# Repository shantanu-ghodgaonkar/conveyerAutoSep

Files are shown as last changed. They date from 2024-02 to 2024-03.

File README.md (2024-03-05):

# conveyerAutoSep

Automatic Package Separator with Arduino
Abstract:

This project builds an innovative Automatic Package Separator system using Arduino technology. It aims to streamline and enhance the efficiency of package segregation based on their addresses.

[Please watch the video by downloading the raw file](IMG_8251.mp4)

Key Components:

Arduino Microcontroller: Manages the system, integrating various components and enabling communication.
1D/2D Barcode Scanner: Uses Waveshare scanner with UART protocol for accurate address reading.
Servo Motors: Control the conveyor system, ensuring precise package movement.
DC Motor: Converts electrical energy into rotational movement for the conveyor.
Ultrasonic Sensor: Measures distances for object detection and avoidance.
LCD Display Module: Provides real-time information.
Operational Overview:

Address Detection: The 2D barcode scanner reads package addresses quickly and accurately.
Conveyor Actuation: Arduino and servo motors control the conveyor. Upon address detection, the motors guide packages towards designated bins.
Segregation Mechanism: Servo motors divert packages to specific bins based on their barcode addresses.
Introduction:

This project addresses the demand for innovative solutions in logistics and supply chain management, specifically focusing on package handling optimization. It introduces an Arduino-driven Automatic Package Separator to revolutionize the process using 1D/2D barcode scanning.

Problem Statement:

Traditional manual sorting processes are time-consuming, error-prone, and resource-intensive. This project aims to automate package segregation based on addresses, mitigating errors and increasing efficiency.

Technological Foundation:

Arduino Uno Microcontroller: The project's core, chosen for its compact size and capabilities.
1D/2D Barcode Scanner (Waveshare): Reads 1D/2D barcodes accurately and efficiently.
Operational Mechanism:

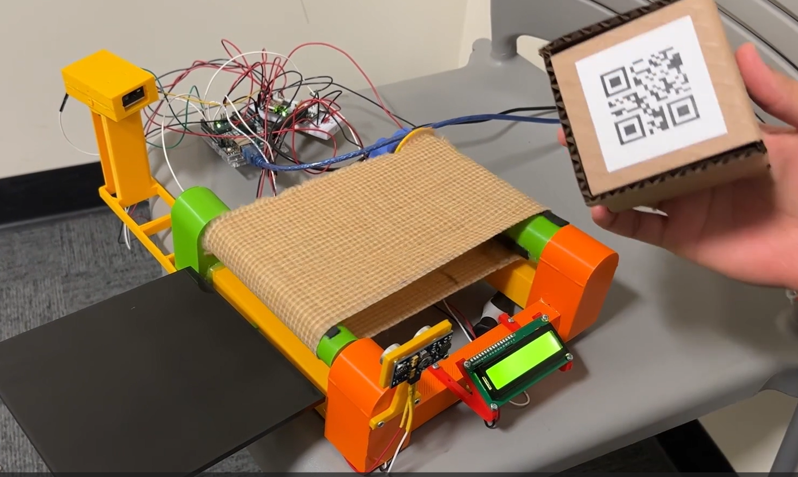
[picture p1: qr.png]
<br/>

Address Detection: The barcode scanner reads package addresses as they pass through the scanning point.
Arduino Uno Control: The Arduino processes scanned information, interpreting the package's destination.
Conveyor Mechanism: A DC motor, controlled by Arduino, actuates the conveyor. Upon address detection, the Arduino commands servo motors to guide the package towards the designated bin.
Segregation Mechanism: A dual-axis turntable with servo motors rotates along two axes, allowing packages to be directed to specific bins.
Components:

Servo Motors: Two control rotation on each axis.
Turntable Platform: Holds the object being rotated.
Turntable Mount: Holds the servo motors, mounted on the conveyor body.
Base Structure: Supports the turntable platform for stability.
Parallax PING))) Ultrasonic Sensor: Measures distances for object detection.
Relay: An electrically operated switch.
LCD Display Module: Provides real-time information.
Technological Choice:

2D barcode scanning is chosen for its proven simplicity and efficiency, enhancing address detection accuracy.

Project Objectives:

Minimize manual effort.
Decrease sorting errors.
Significantly improve speed and accuracy.
Future Enhancements:

Machine Learning Integration: Optimize sorting algorithms based on data, package types, and destinations.
Robotics Integration: Explore robots for automated package handling.
Cascaded Network of Modules: Integrate multiple systems for multilevel sorting.
This document serves as a comprehensive overview of the Automatic Package Separator project. It details the system design, functionalities, and potential future enhancements.

Segregation for Brooklyn-
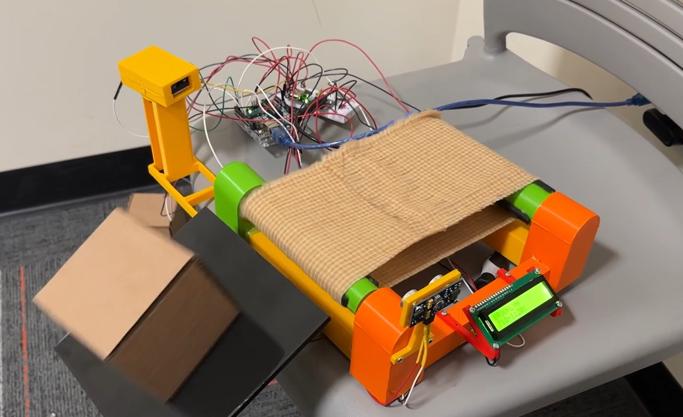
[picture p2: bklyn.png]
<br/>

Segregation for Manhattan-
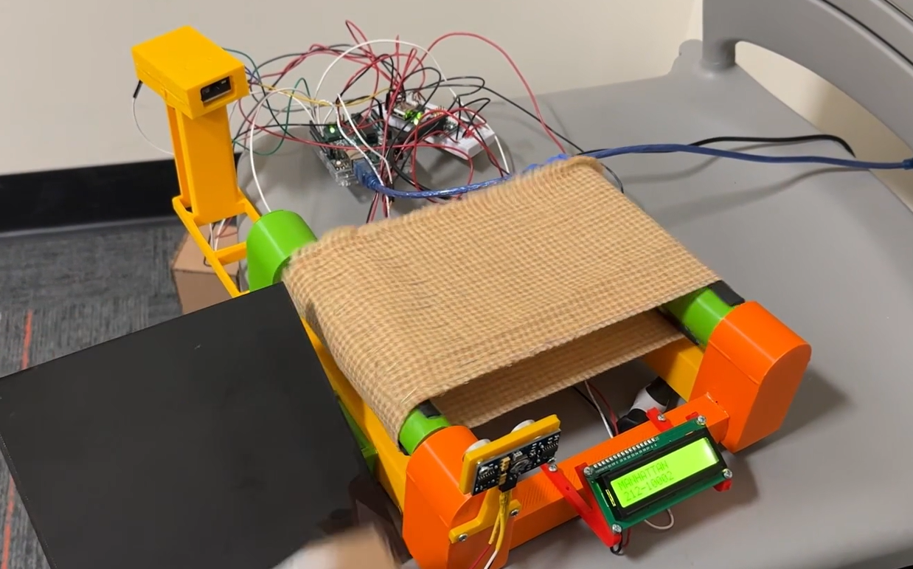
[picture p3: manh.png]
<br/>

Segregation for Queens-
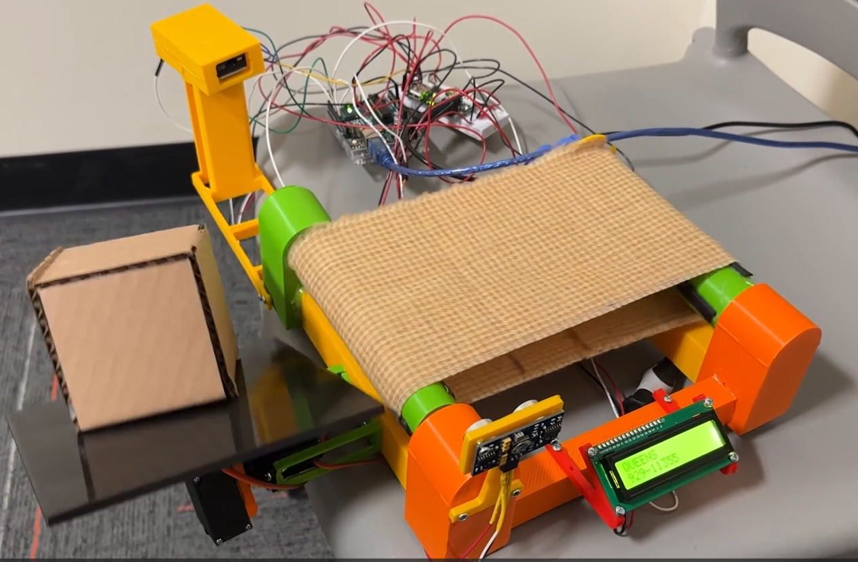
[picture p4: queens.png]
<br/>

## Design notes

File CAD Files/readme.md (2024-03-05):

This folder stores all the CAD files for building the conveyer system.

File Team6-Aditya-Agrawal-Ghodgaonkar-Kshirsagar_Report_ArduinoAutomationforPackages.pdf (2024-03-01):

# Automated Package Separator

By:

Shantanu Ghodgaonkar | - | sng8399, N11344563
Hemant Agarwal | - | hra5704, N10037896
Mihir Kshirsagar | - | msk9917, N16144406
Aditya Abishai Pedapati | - | aap9224, N15101231

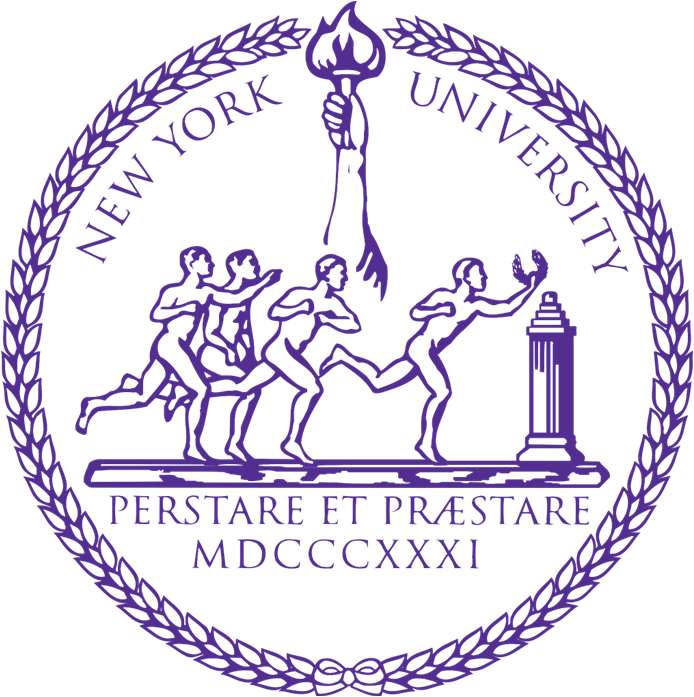
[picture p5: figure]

## New York University, Tandon School of Engineering Department of Mechanical and Aerospace Engineering Advanced Mechatronics ROB-GY6103 Term Project -1

1

CONTENTS

### 1. Acknowledgements 2. Abstract

a. Key Components
b. Operational Overview

### 3. Introduction 4. Problem Statement 5. Technological Foundation

a. 1D/2D Barcode Scanner
b. Operational Mechanism
c. Arduino Uno Control
d. Conveyer Mechanism
e. Segregation Mechanism
i. Components of Segregation Mechanism

### 1. Turntable Platform 2. Turntable mount 3. Base Structure

f. Parallax PING)))
g. Relay
h. LCD Display Module

### 6. Technological Choice 7. Project Objectives 8. Circuit Schematics 9. Flowcharts

10.Applications
11.Future Enhancements
12.References

2

Acknowledgements
We extend our heartfelt gratitude to Professor Vikram Kapila PhD, for his invaluable mentorship and scholarly guidance throughout our academic journey. His expertise and dedication have inspired us, shaping our understanding and passion for the subject.

To our teammates, Shantanu Ghodgaonkar, Mihir Kshirsagar, Hemant Agarwal and Aditya Abishai P we appreciate the collaborative effort and camaraderie that made our academic endeavors even more rewarding.

This journey would not have been possible without the support and encouragement of these exceptional individuals. Thank you for being constant pillars of knowledge and inspiration in our academic endeavors."

Abstract

This project revolves around the development of an innovative Automatic Package Separator system using Arduino technology. The primary objective is to streamline and enhance the efficiency of package segregation based on their respective addresses.

Key Components:

Arduino Microcontroller: The core of the system, managing the integration of various components and facilitating seamless communication.
1D/2D Barcode Scanner (Waveshare): Utilizing the Waveshare barcode scanner with UART communication protocol for accurate and efficient address detection.
Servo Motors: Employing multiple servo motors to actuate the conveyor system, ensuring precise and controlled movement of packages.
DC Motor: A DC motor converts direct current (DC) electrical energy into rotational mechanical energy
Ultrasonic Sensor: The Parallax PING))) Ultrasonic Sensor utilizes ultrasonic sound waves to measure distances and is commonly employed for object detection, navigation, and avoidance in various projects.
LCD Display Module: An LCD (Liquid Crystal Display) module is a versatile electronic visual display that is commonly used to provide real-time information in various devices.

Operational Overview:

1D/2D Barcode Address Detection: The system employs a 2D barcode scanner for quick and accurate reading of package addresses. The simplicity and efficiency of 2D barcodes contribute to the speed and reliability of the detection process.
Conveyor Actuation: Arduino, in collaboration with servo motors, controls the conveyor system. Upon successful address detection, the servo motors activate, guiding the packages towards their designated bins for further processing.
Segregation Mechanism: The servo motors play a crucial role in diverting packages to specific bins based on their 1D barcode addresses. This automated approach ensures a systematic and errorfree package segregation process.

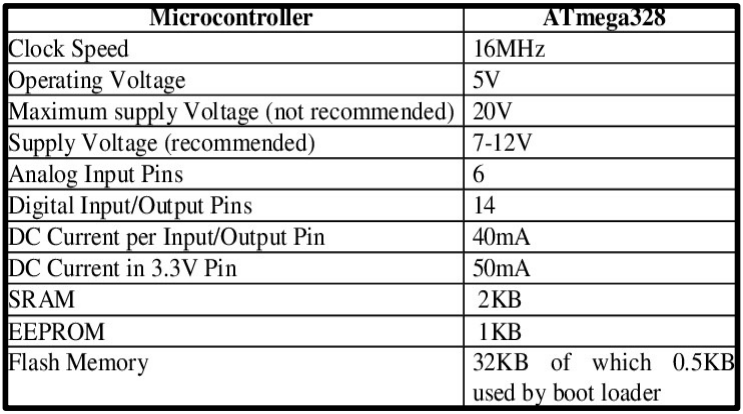
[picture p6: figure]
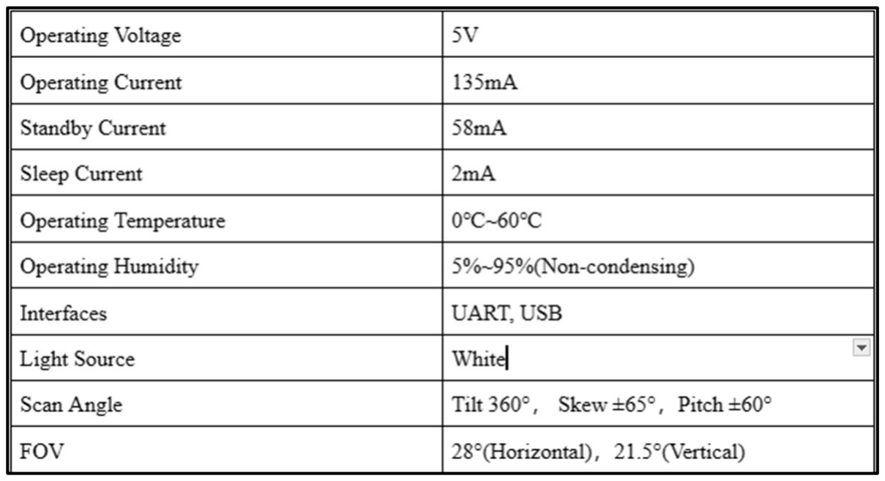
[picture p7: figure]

3

- Introduction

In the dynamic landscape of logistics and supply chain management, the demand for innovative solutions to optimize package handling has never been more critical. This project endeavors to meet this demand by introducing an Automatic Package Separator, a sophisticated system driven by Arduino Uno, designed to revolutionize the segregation process through the incorporation of a 1D/2D barcode scanner.

- Problem Statement
Traditional manual sorting processes are inherently time-consuming, error-prone, and resourceintensive. In response to these challenges, our project aims to automate the segregation of packages based on their addresses, mitigating errors and significantly increasing operational efficiency.
- Technological Foundation

Arduino Uno Microcontroller: At the core of our system lies the Arduino Uno, a versatile and widely-used microcontroller. Its compact size and capabilities make it a suitable choice for coordinating the various components of our Automatic Package Separator.

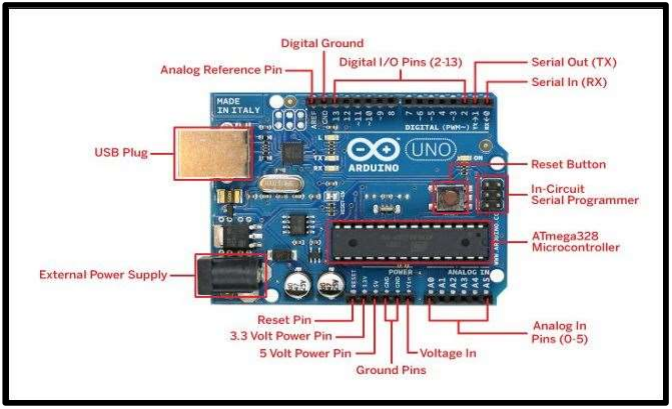
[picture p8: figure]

- 1D/2D Barcode Scanner (Waveshare)
The heart of our address detection mechanism is the Waveshare 1D/2D barcode scanner, utilizing a UART communication protocol. This scanner is strategically chosen for its accuracy, efficiency, and simplicity in reading 1D/2D barcodes.

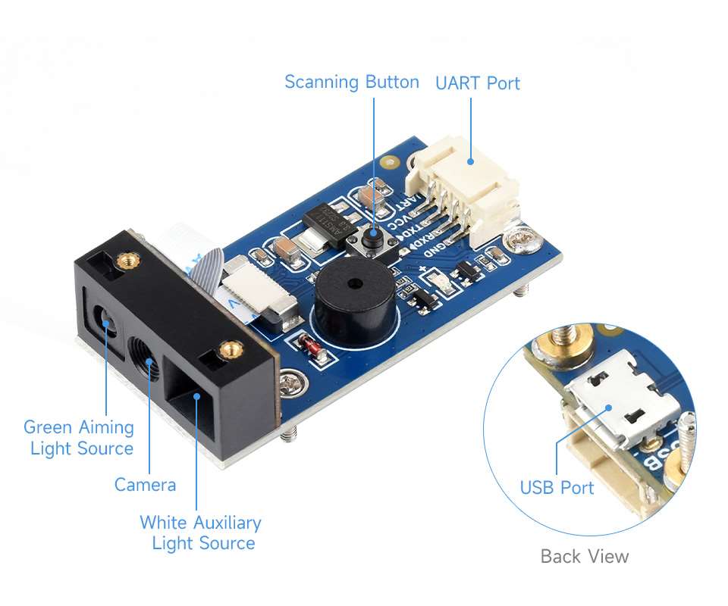
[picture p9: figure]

Specifications of the Barcode scanner

4

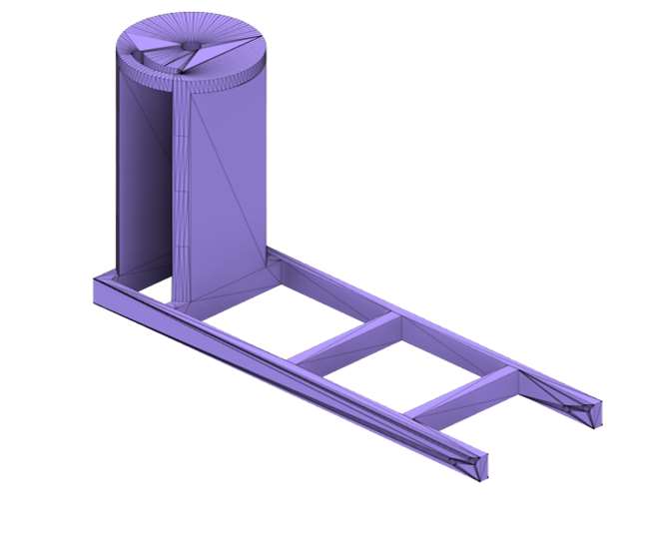
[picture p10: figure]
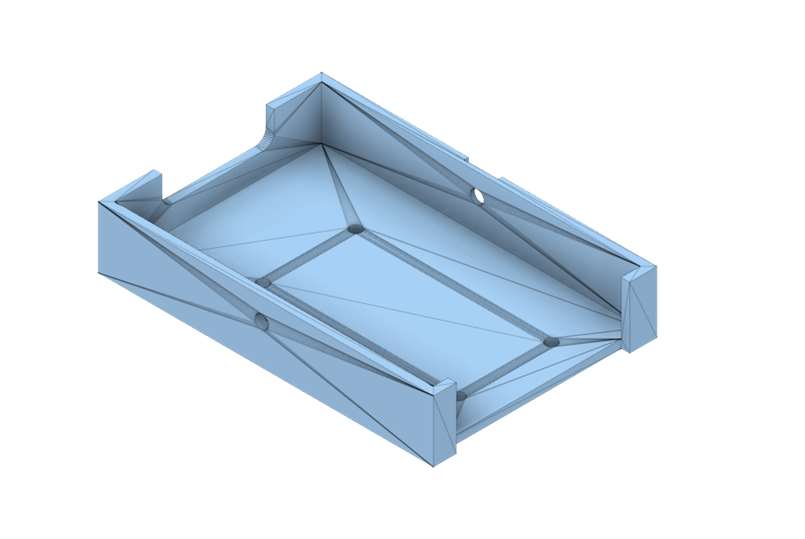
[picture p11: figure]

barcode scanner housing | Barcode scanner mount
- Operational Mechanism

Address Detection: The 1D/2D barcode scanner is integrated into the system to facilitate the swift and accurate reading of package addresses. As a package passes through the scanning point, the barcode scanner decodes the information embedded in the 2D QR code.

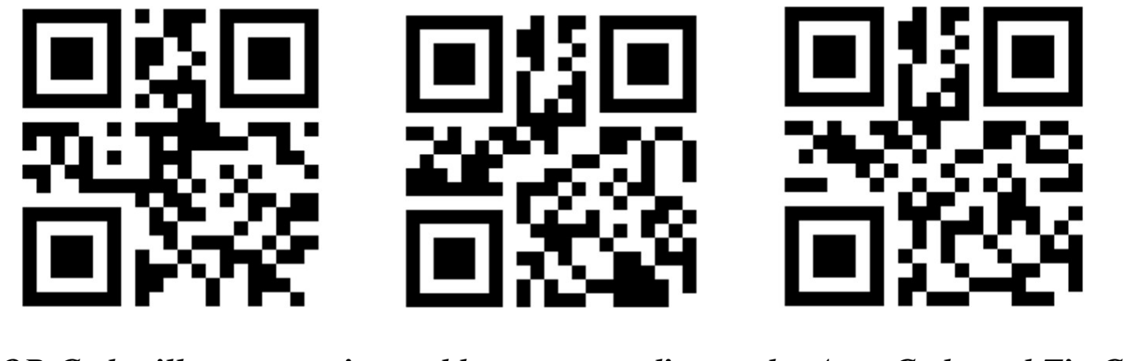
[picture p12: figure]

The QR Codes illustrate various addresses according to the Area Code and Zip Code of NYC’s Brooklyn(718-11201), Queens(929-11355) and Manhattan(212-10002)

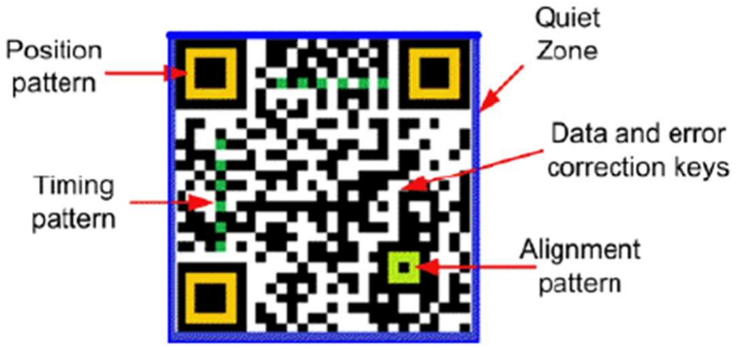
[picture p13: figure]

- Arduino Uno Control
The Arduino Uno processes the information received from the barcode scanner, leveraging its processing power to interpret the package's destination based on the scanned address. This information serves as the trigger for the subsequent stages of the segregation process.

5

- Conveyor Mechanism
One DC motor, intricately connected to the Arduino Uno, is employed to actuate the conveyor system. Upon successful address detection, the Arduino commands the servo motors to guide the package towards its designated bin.

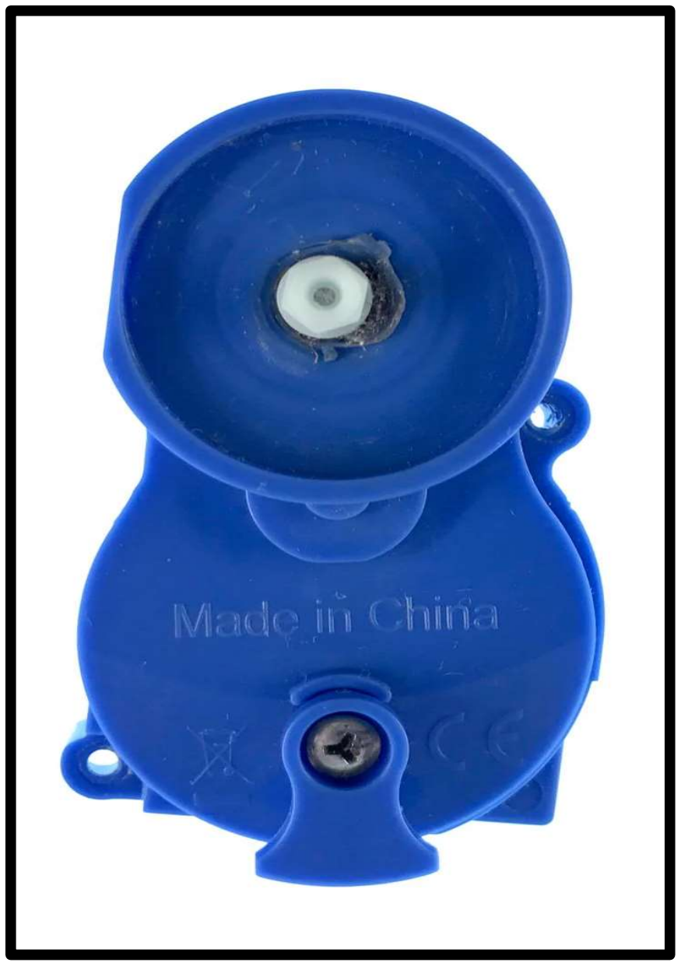
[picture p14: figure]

- Segregation Mechanism

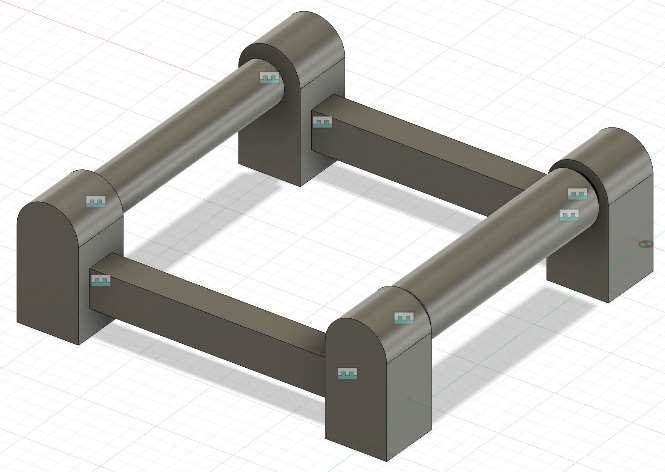
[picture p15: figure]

A dual-axis turntable with servomotors is a mechanism that allows for rotation along two independent axes. This type of system is commonly used in applications such as robotics, photography, or any scenario where precise control of rotation in two dimensions is required.

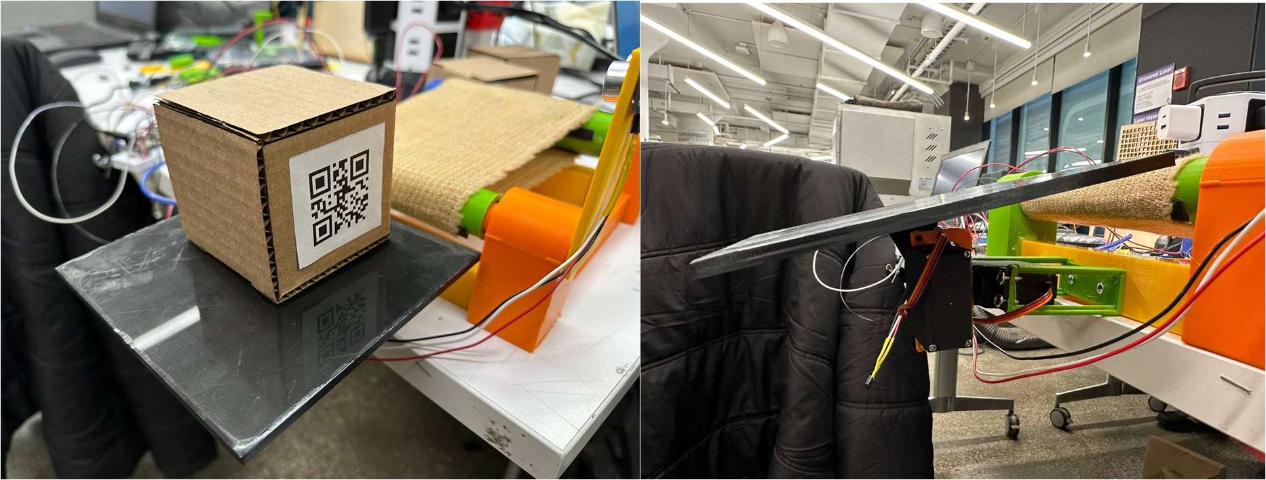
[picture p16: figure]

Image illustrates the segregation mechanism employed by two servos

Components of the segregation mechanism

- Servo Motors:
Two servo motors are used, each responsible for controlling rotation along one axis.
Servo Motors are preferred due to their precision, ease of control, and ability to maintain specific positions.

6

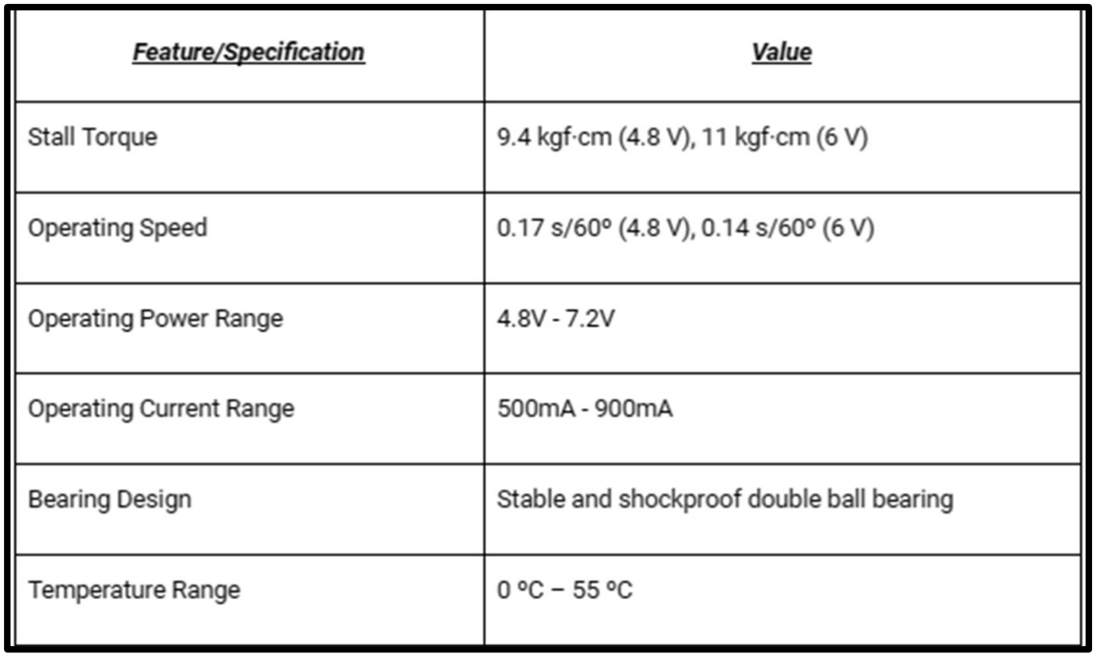
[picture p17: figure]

Specs of MG 996R servo motor

- Turntable Platform:
The turntable platform is the surface on which the object or device is placed for rotation.
It should be designed to handle the weight and size of the objects being rotated. This was designed in CAD and was later 3D printed.

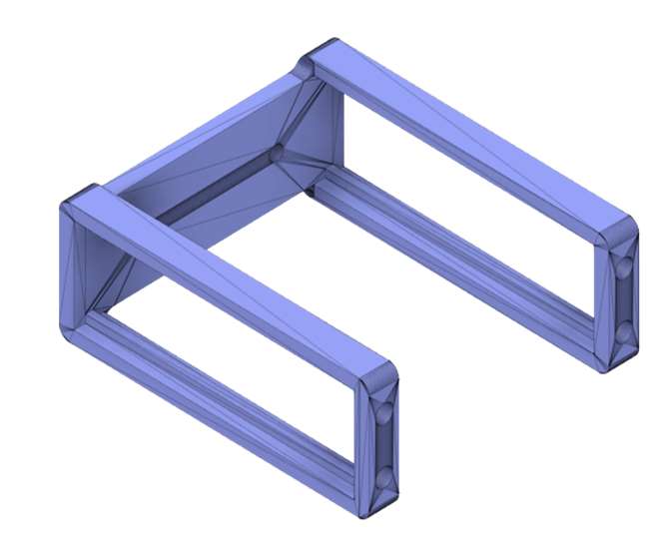
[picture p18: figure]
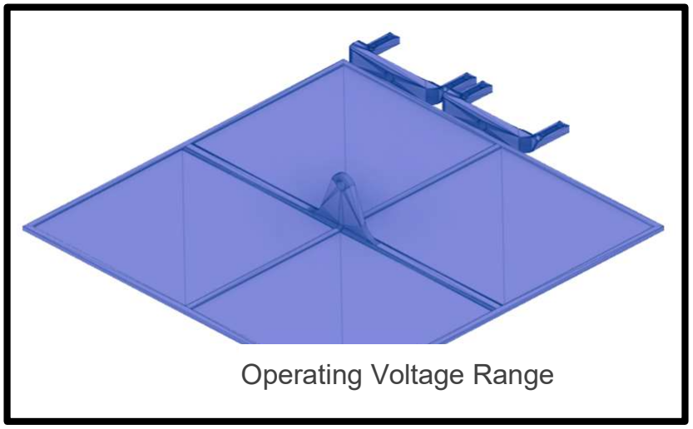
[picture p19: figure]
Operating Voltage Range

Tilt-table & Tilt-table Servo Mount

- Turntable mount:
A mount was designed in CAD which will help in holding the servo motors. This mount will be mounted on the conveyor body. ● Base Structure:

The base structure holds and supports the turntable platform, ensuring stability during rotation. It may include bearings or other mechanisms to reduce friction and facilitate smooth rotation.

- Parallax PING)))
The Parallax PING))) Ultrasonic Sensor is a popular ultrasonic range finder used in robotics and automation applications. It utilizes ultrasonic sound waves to measure distances and is commonly employed for object detection, navigation, and avoidance in various projects.

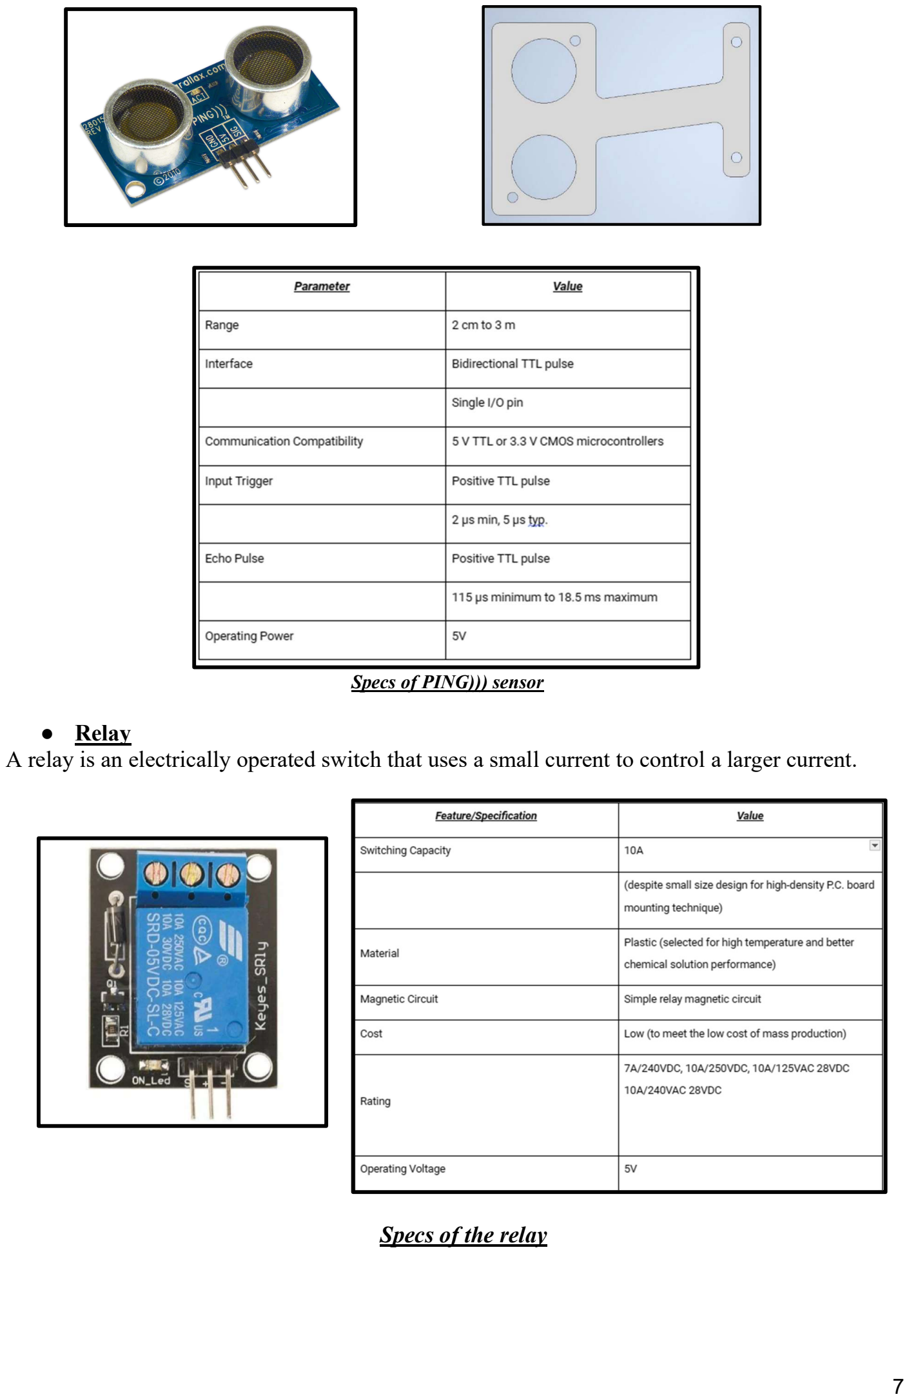
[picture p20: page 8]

7

Specs of PING))) sensor

- Relay
A relay is an electrically operated switch that uses a small current to control a larger current.

Specs of the relay

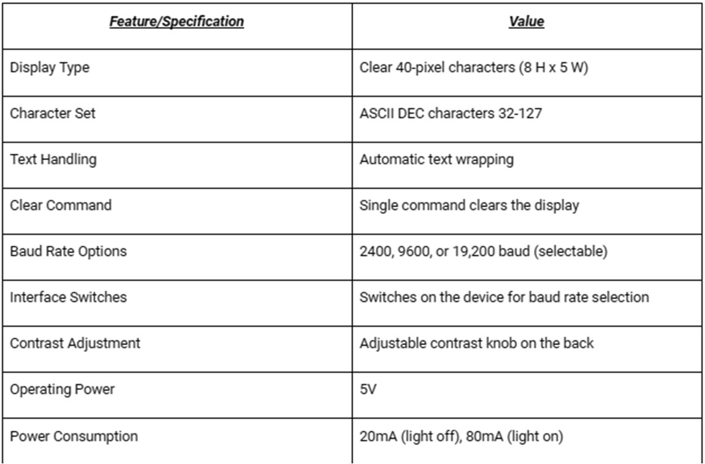
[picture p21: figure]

8

- LCD Display Module

An LCD (Liquid Crystal Display) module is a versatile electronic visual display that is commonly used to provide real-time information in various devices.

Specs of the LCD module

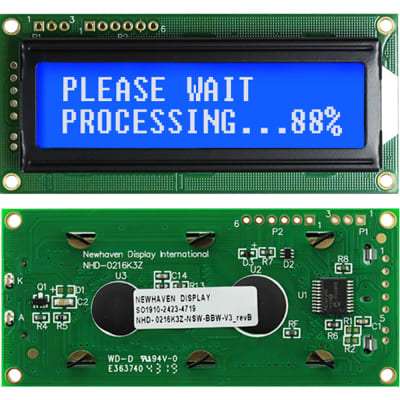
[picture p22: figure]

- Technological Choice:
The decision to employ 2D barcode scanning over alternative methods is grounded in the technology's proven simplicity and efficiency. By opting for 2D barcodes or QR codes, we enhance the overall precision of address detection, a crucial factor in the success of our Automatic Package Separator.
- Project Objectives:
This project seeks to minimize manual efforts, decrease the occurrence of sorting errors, and significantly improve the speed and accuracy of the package handling process. Through the integration of advanced technologies, we aspire to set a new standard for automated logistics solutions.

As we delve deeper into the subsequent sections of this report, we will provide detailed insights into the system design, operational functionalities, and potential avenues for future enhancements, showcasing the meticulous planning and execution that underpins the success of our Automatic Package Separator.

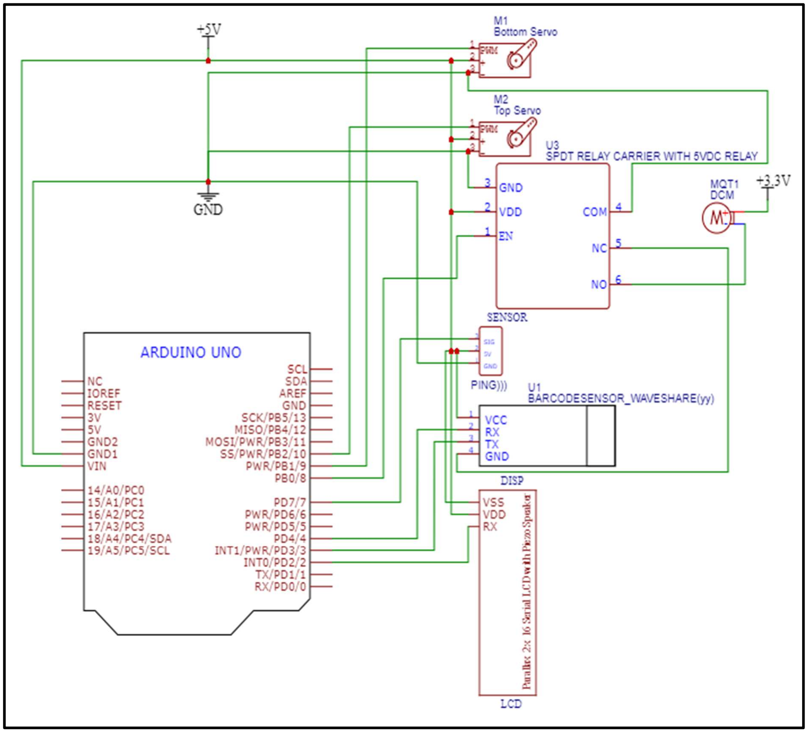
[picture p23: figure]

9

Circuit Schematic

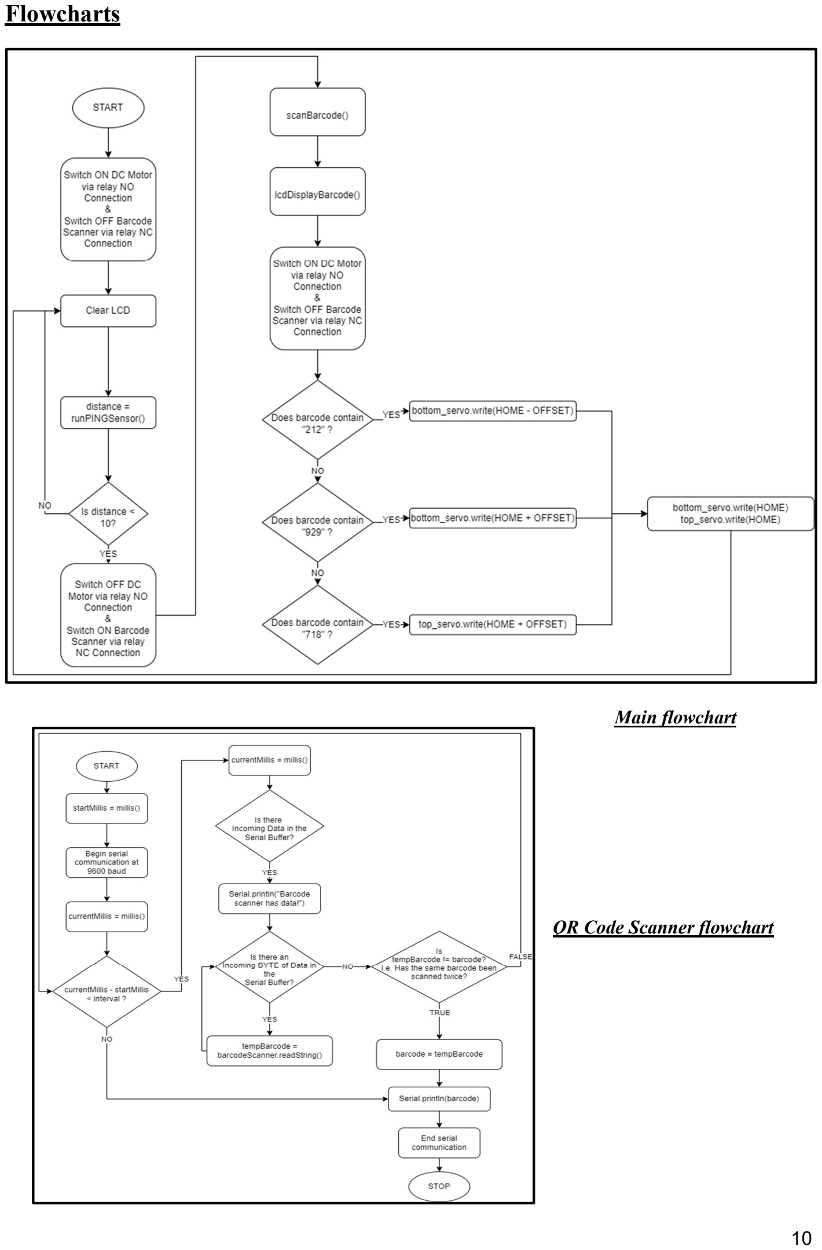
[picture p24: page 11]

10

Flowcharts

Main flowchart

QR Code Scanner flowchart

11

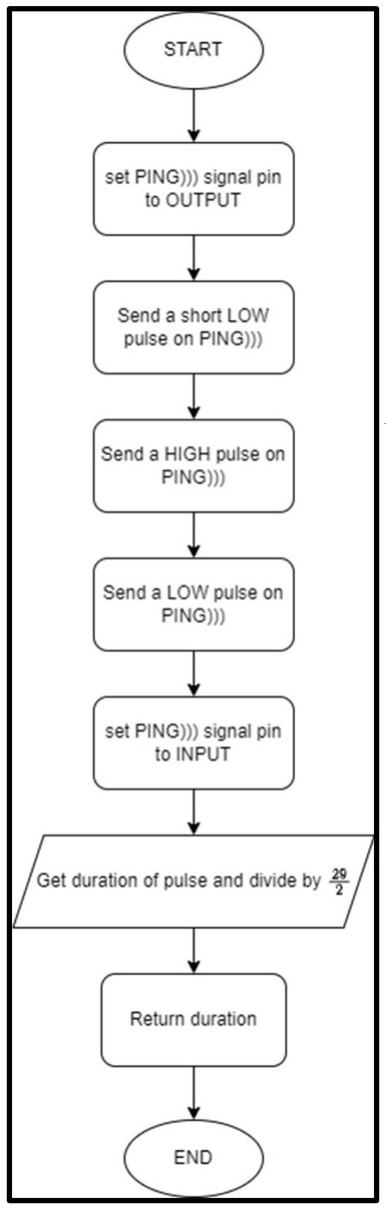
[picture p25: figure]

Applications:

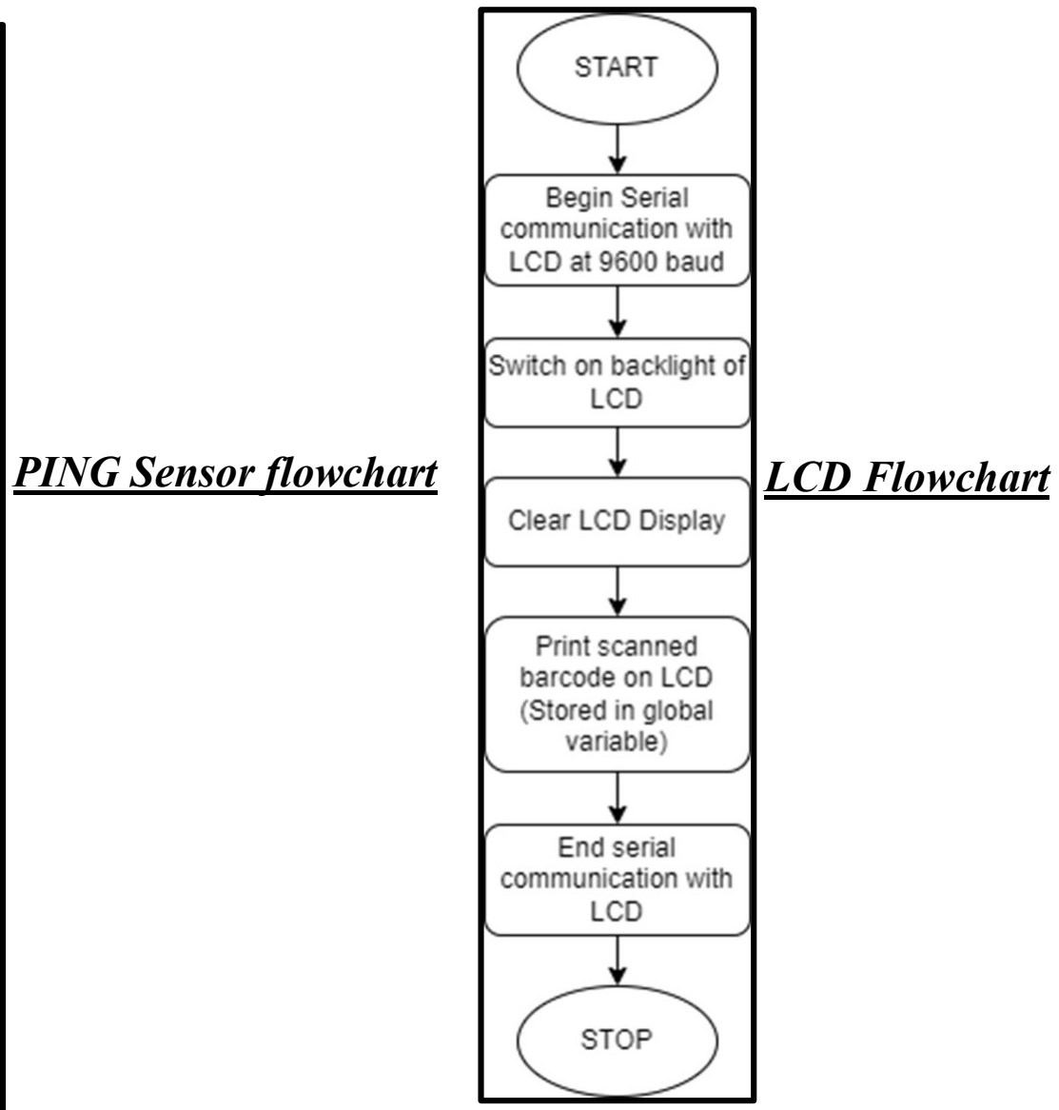
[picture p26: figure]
PING Sensor flowchart; LCD Flowchart

### 1. E-commerce warehousing: In e-commerce fulfillment centers, an intelligent package

sorter streamlines the sorting and routing of packages, ensuring timely and accurate deliveries.The system can handle a high volume of packages with different sizes and destinations efficiently.

2. Distribution Centers: Distribution centers for retail, manufacturing, or any industry can benefit from an intelligent package sorter to automate the sorting process, reducing manual labor and minimizing errors.
3. Postal Services: National and international postal services can utilize intelligent package sorters to enhance the speed and accuracy of package sorting, leading to faster and more reliable deliveries.

12

Future Enhancements

### 1. Machine Learning Integration: Implement machine learning algorithms to continuously

optimize sorting algorithms based on historical data, package types, and destination patterns. This can enhance predictive sorting accuracy.

2. Robotics Integration: Explore the integration of robotics for more automated handling of packages. Robots could assist in loading and unloading packages onto conveyor systems, further reducing the need for manual labor.

### 3. Cascaded Network of Modules: Each such system can be considered as a module and

many such modules can be integrated and synchronized for multilevel sorting. Its working would be akin to that of transistors in a processor.

References

- https://how2electronics.com/barcode-qr-code-reader-using-arduino-qrscanner-module/
- https://files.waveshare.com/upload/d/dd/Barcode_Scanner_Module_Setting_Manual_EN.pdf
- https://github.com/iamthechad/parallax_lcd
- https://github.com/arduino/ArduinoCoreavr/blob/master/libraries/SoftwareSerial/src/SoftwareSerial.h
- https://www.arduino.cc/reference/en/libraries/servo/
- https://docs.arduino.cc/built-in-examples/sensors/Ping/
- https://grabcad.com/library/gm66-qr-barcode-scanner-1
- https://www.qr-code-generator.com/

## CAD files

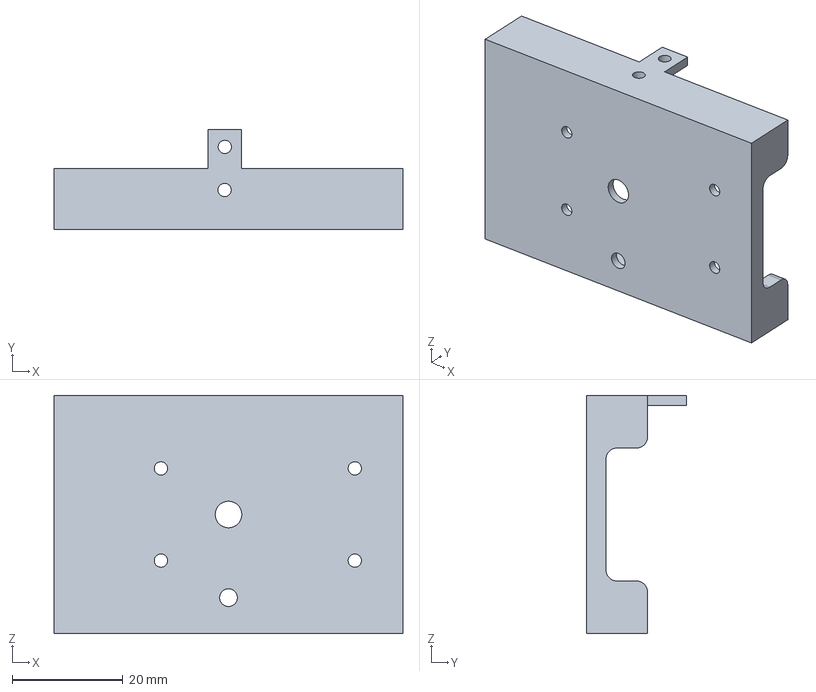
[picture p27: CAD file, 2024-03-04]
CAD Files/bottom_case.stp
63.0 x 18.0 x 43.0 mm

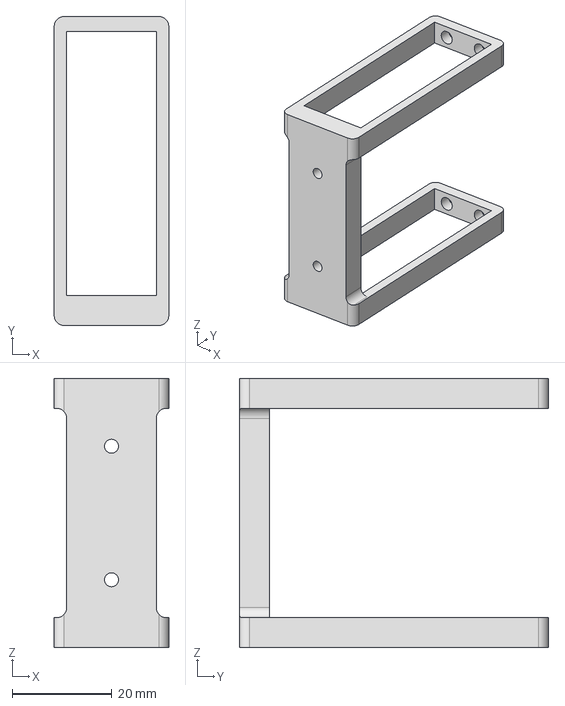
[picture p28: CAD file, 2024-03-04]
CAD Files/TurnTable_Mount.stp
23.0 x 62.0 x 54.0 mm

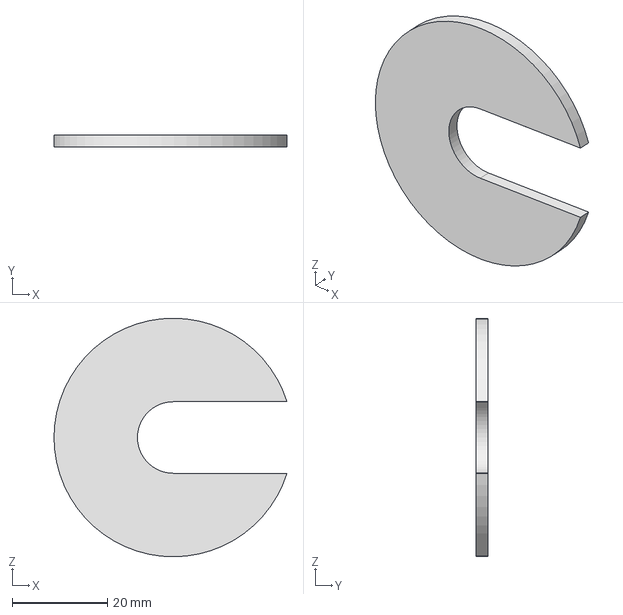
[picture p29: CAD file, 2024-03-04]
CAD Files/BeltStopper.stp
48.8 x 2.50 x 50.0 mm

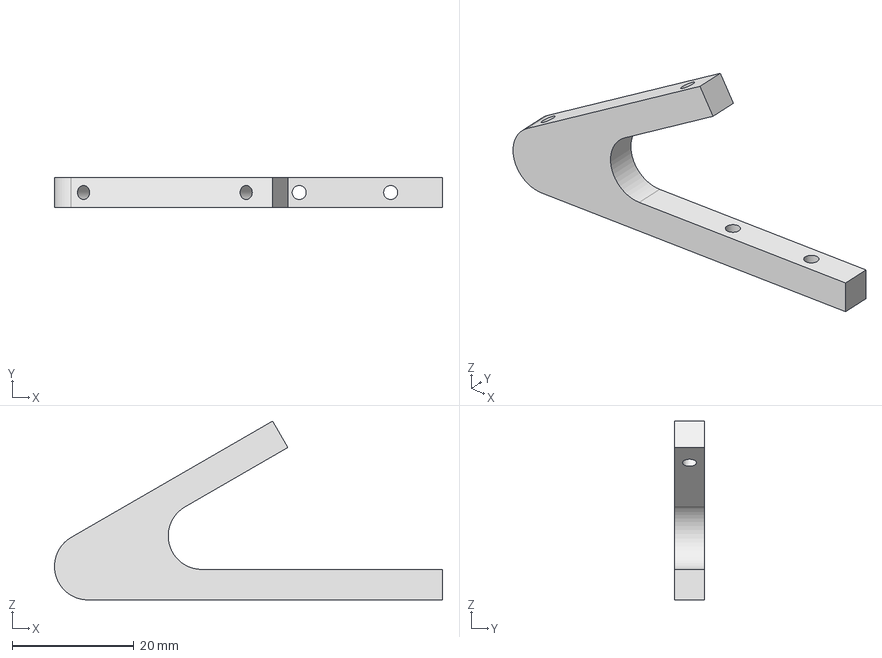
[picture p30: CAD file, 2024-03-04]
CAD Files/LCD_Mount.stp
63.6 x 5.00 x 29.3 mm

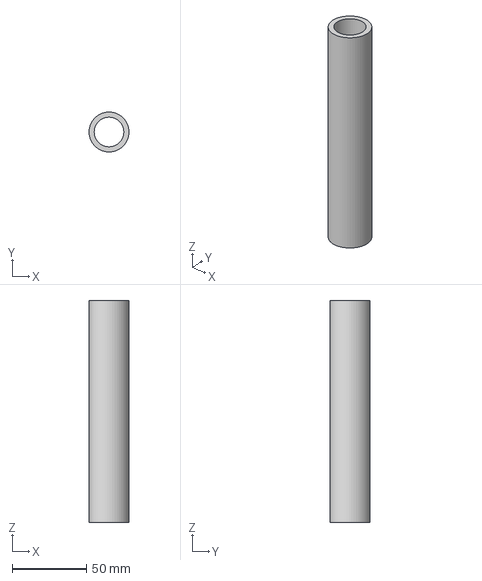
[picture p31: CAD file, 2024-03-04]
CAD Files/Driven Roller v2.step
27.0 x 27.0 x 150.0 mm

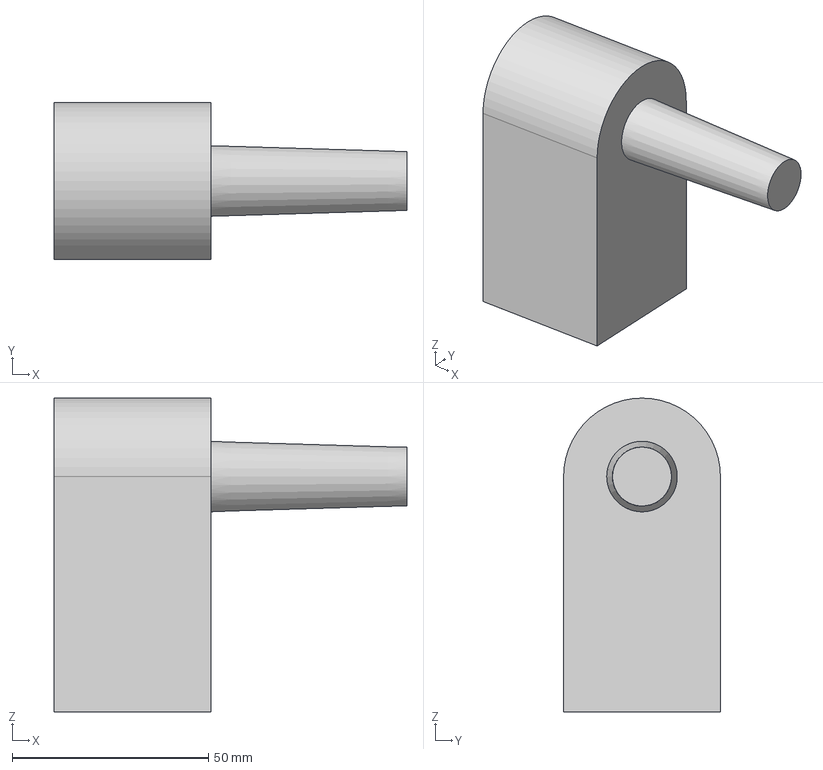
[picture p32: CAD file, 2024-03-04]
CAD Files/Roller Holder v2.step
90.0 x 40.0 x 80.0 mm

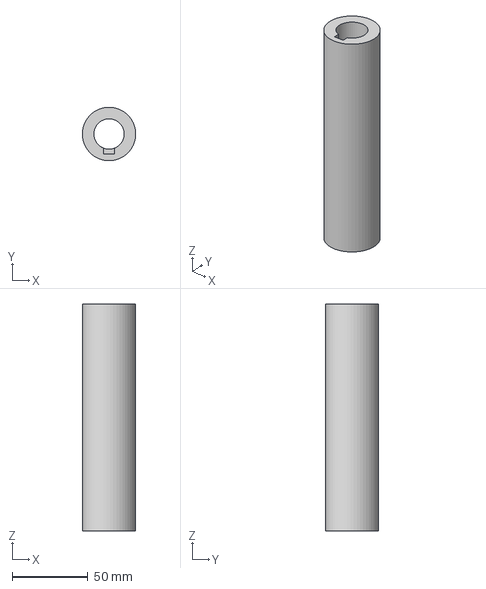
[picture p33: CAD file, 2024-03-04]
CAD Files/Roller v9.step
35.3 x 35.3 x 150.0 mm

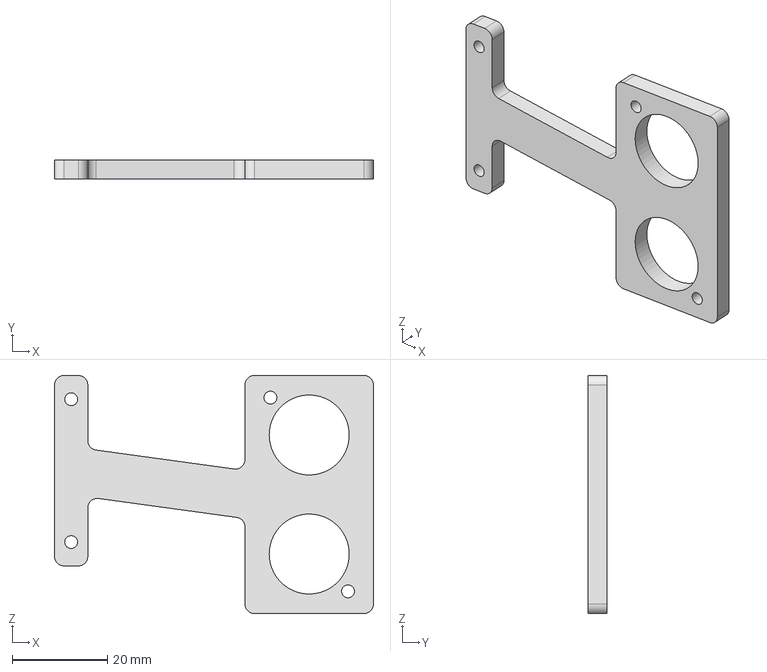
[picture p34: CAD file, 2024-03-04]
CAD Files/Ultrasonic Mount.stp
67.0 x 4.00 x 50.0 mm

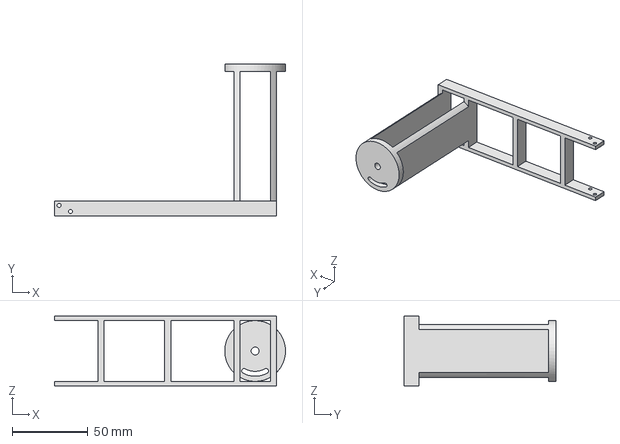
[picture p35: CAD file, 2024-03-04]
CAD Files/Barcode_Mount.stp
152.0 x 100.0 x 46.0 mm

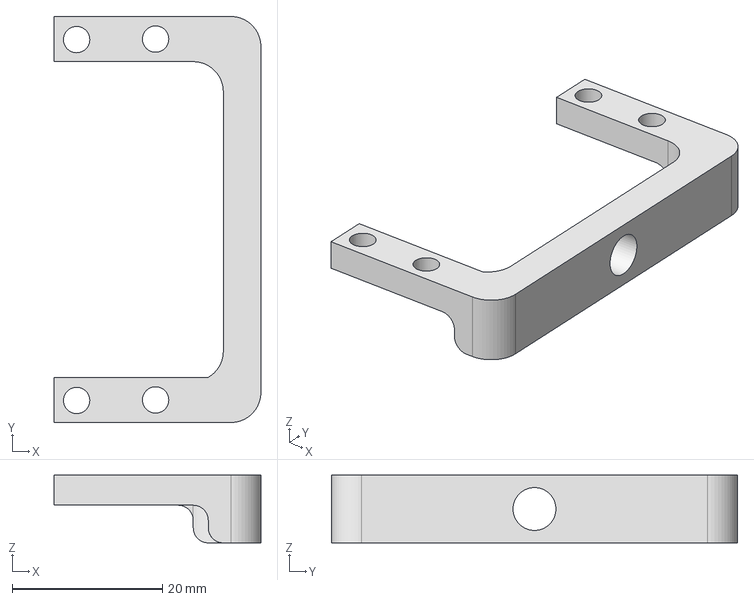
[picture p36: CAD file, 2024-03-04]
CAD Files/Servo_Mount_Turntable_V1.stp
27.5 x 54.0 x 9.00 mm

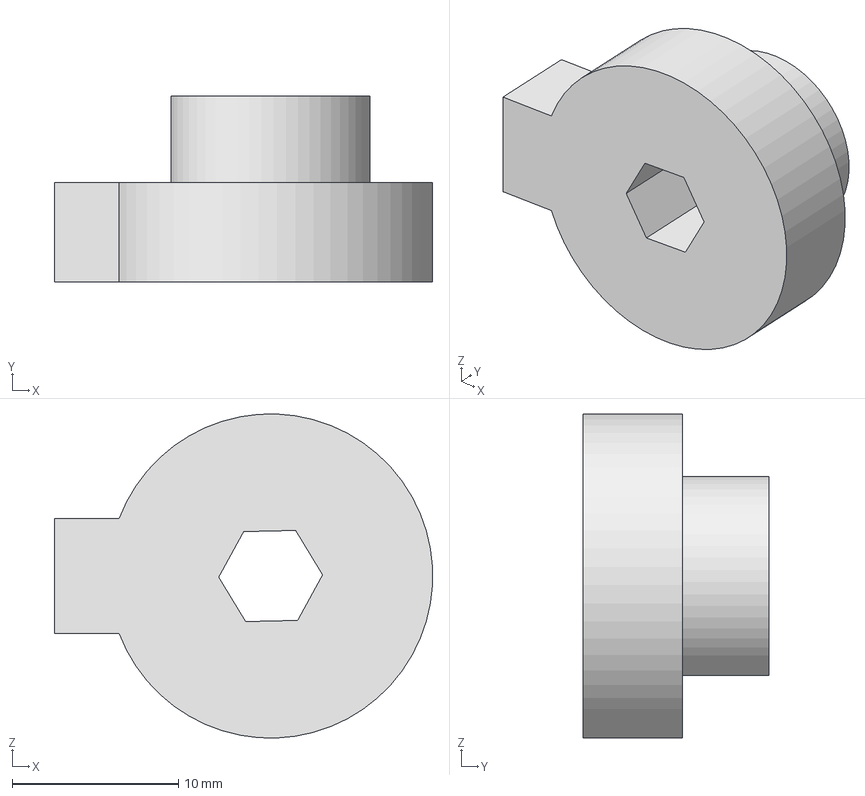
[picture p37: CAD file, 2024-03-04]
CAD Files/HexKey.stp
22.7 x 11.2 x 19.5 mm

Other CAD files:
CAD Files/TopCase.stp

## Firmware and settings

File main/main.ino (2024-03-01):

#include <SoftwareSerial.h>
#include <string.h>
#include <ParallaxLCD.h>
#include <Servo.h>
#include <Regexp.h>

// Pins
#define PINGSENSOR 7  // PING Sensor on Pin 7
#define DCMRELAY 8    // DC Motor relay on Pin 8
#define TOPSERVO 10   // Top Mounted Servo on Pin 10
#define BOTSERVO 9    // Bottom Mounted Servo on Pin 9
#define LCD 2         // LCD on Pin 2
#define BCSTX 3       // Barcode Scanner Transmitter
#define BCSRX 4       // Barcode Scanner Receiver

// LCD Constants
#define ROWS 2        // Number of rows in LCD
#define COLS 16       // Number of columns in LCD

// Servo motor Constants
#define BOTSERVOHOME 90   // Bottom Servo Home Angle
#define TOPSERVOHOME 105   // Top Servo Home Angle
#define SERVOOFFSET 30    // Servo Offset Angle

SoftwareSerial barcodeScanner(BCSTX, BCSRX); // Declare Barcode Scanner as a serial device
ParallaxLCD lcd(LCD,ROWS,COLS); // Declare Parallax LCD as a serial device
Servo botServo; // Declare bottom servo
Servo topServo; // Declare top servo
long distance = 0; // Variable to store output of PING sensor in cm
String barcode = "NONE";  // Variable to store scanned barcode
String tempBarcode = "NONE"; // Variable to store temporarily scanned barcode for comparison
unsigned long startMillis = 0; // Variable to store the millis() when scanBarcode() is called
unsigned long interval = 4000; // Variable to store the interval for which the barcode is to be switched on
unsigned long currentMillis = 0; // Variable to store the current value of millis() to check how long the barcode scanner has been switched on for

long runPINGSensor() { // This function is responsible to get sensordata from PING sensor 
 // The PING))) is triggered by a HIGH pulse of 2 or more microseconds.
  // Give a short LOW pulse beforehand to ensure a clean HIGH pulse:
  pinMode(PINGSENSOR, OUTPUT);
  digitalWrite(PINGSENSOR, LOW);
  delayMicroseconds(2);
  digitalWrite(PINGSENSOR, HIGH);
  delayMicroseconds(5);
  digitalWrite(PINGSENSOR, LOW);

  // The same pin is used to read the signal from the PING))): a HIGH pulse
  // whose duration is the time (in microseconds) from the sending of the ping
  // to the reception of its echo off of an object.
  pinMode(PINGSENSOR, INPUT);
  return pulseIn(PINGSENSOR, HIGH) / 29 / 2;
}

void scanBarcode() { // This function is responsible to get the scanned barcode in string form
  startMillis = millis(); // Note the time at which this fucntion is called
  barcodeScanner.begin(9600);
  currentMillis = millis(); // Initialise this variable appropriately so that the while loop can be entered
  while(currentMillis - startMillis < interval){ // Check how much time has passed and whether it is less than the chosen interval
    currentMillis = millis(); // Note current time elapsed
    if (barcodeScanner.available()) // Check if there is Incoming Data in the Serial Buffer.
    { Serial.println("Barcode scanner has data!"); 
      while (barcodeScanner.available()) // Keep reading Byte by Byte from the Buffer till the Buffer is empty
      {tempBarcode = barcodeScanner.readString();
      // barcode = barcodeScanner.readString();
      } // Store current read barcode in a temporary variable
    }
    if(tempBarcode[3] == '-'){
      if(tempBarcode != barcode) { // Check if same barcode has not been read twice
        barcode = tempBarcode; // Update barcode variable
        break; // Exit while loop
      }
    }
  }
  Serial.println(barcode); // Print read barcode
  barcodeScanner.end(); // End serial communication
}

void lcdDisplayBarcode() {
  lcd.setup(); // setup LCD
  lcd.backLightOn(); // Switch on LCD backlight
  lcd.empty(); // Clear LCD Screen
  // lcd.print("Scanned Barcode: "); // Display scanned barcode on LCD
  // lcd.print(barcode);
  if(barcode.substring(0,3) == "212") lcd.print("MANHATTAN");
  else if (barcode.substring(0,3) == "929") lcd.print("QUEENS"); // Check for second area and rotate servos accordingly
  else if (barcode.substring(0,3) == "718") lcd.print("BROOKLYN"); // Check for third area and rotate servos accordingly
  lcd.cr();
  lcd.print(barcode);
  delay(1500);
  lcd.end();
}

void setup() {
  botServo.attach(BOTSERVO); // Attach bottom servo to pin 9
  topServo.attach(TOPSERVO); // Attach top servo to pin 10
  botServo.write(BOTSERVOHOME); // Set bottom servo to home configuration
  topServo.write(TOPSERVOHOME); // Set top servo to home configuration
  pinMode(DCMRELAY, OUTPUT); // Set DC motor Relay pin as output
  digitalWrite(DCMRELAY, HIGH); // Switch on DC motor
  Serial.begin(9600); // Start serial communication
  // barcodeScanner.begin(115200);
}

void loop() {
  lcd.empty(); // Clear LCD Screen
  distance = runPINGSensor(); // Get PING Sensor reading
  if(distance < 10){ // If distance is less than 10 cm, package is in postion to be scanned
    digitalWrite(DCMRELAY, LOW); // Switch off motor; switch on barcode scanner
    scanBarcode(); // Scan barcode
    lcdDisplayBarcode(); // Display scanned barcode on LCD
    digitalWrite(DCMRELAY, HIGH); // Switch on DC motor; switch off barcode scanner
    delay(1000); // Wait for package to fall on turntable
    if(barcode.substring(0,3) == "212") botServo.write(BOTSERVOHOME - SERVOOFFSET); // Check for first area and rotate servos accordingly
    else if (barcode.substring(0,3) == "929") botServo.write(BOTSERVOHOME + SERVOOFFSET); // Check for second area and rotate servos accordingly
    else if (barcode.substring(0,3) == "718") topServo.write(TOPSERVOHOME - SERVOOFFSET); // Check for third area and rotate servos accordingly
    delay(1000); // Allow 1s of delay for package to fall into right box
    botServo.write(BOTSERVOHOME); // Bring bottom servo back to home
    topServo.write(TOPSERVOHOME); // Bring top servo back to home
    barcode = "NONE";
    tempBarcode = "NONE";
  }
}

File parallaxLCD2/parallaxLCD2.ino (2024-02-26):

#include <ParallaxLCD.h>

// Change these values if you're using the 4x20 LCD
#define ROWS 2
#define COLS 16

ParallaxLCD lcd(2,ROWS,COLS); // desired pin, rows, cols

void setup () {

  lcd.setup();
  lcd.backLightOn();
  lcd.empty();
  Serial.begin(9600);
}
void loop () {
  Serial.println("LCD SETUP BEGIN");
  lcd.setup();
  lcd.backLightOn();
  lcd.empty();
  Serial.println("LCD COMMS STARTED");
  delay(1000);
  lcd.print("Scanned Barcode: ");
  lcd.print("212-11219");
  delay(3000);
  // lcd.empty();
  lcd.end();
  Serial.println("LCD COMMS ENDED");
  delay(3000);
}

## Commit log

2024-03-03 Created folder for adding CAD files
2024-03-04 Uploaded all CAD files
    [Barcode_Mount.stp, BeltStopper.stp, Driven Roller v2.step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]
